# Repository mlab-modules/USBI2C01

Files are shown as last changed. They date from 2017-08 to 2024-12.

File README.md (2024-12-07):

# USBI2C01A - USB to I²C master converter

USBI2C01A is USB to I²C master adapter, it provides you ability to connect almost any I2C/SMBUS sensor or other device to a computer trought USB.
Converter is based on [CP2112](https://www.silabs.com/interface/usb-bridges/classic/device.cp2112?tab=specs) integrated USB brigde with native Linux kernel support. 
Therefore device create kernel accesible I2C interface intstantly on almost any Linux distributions.
If your computer doesn't support CP2112 converter, it's possible to use the USB-HID interface of the converter.
Thanks to that, the device can be used with other operating systems as well, as Windows or Android.

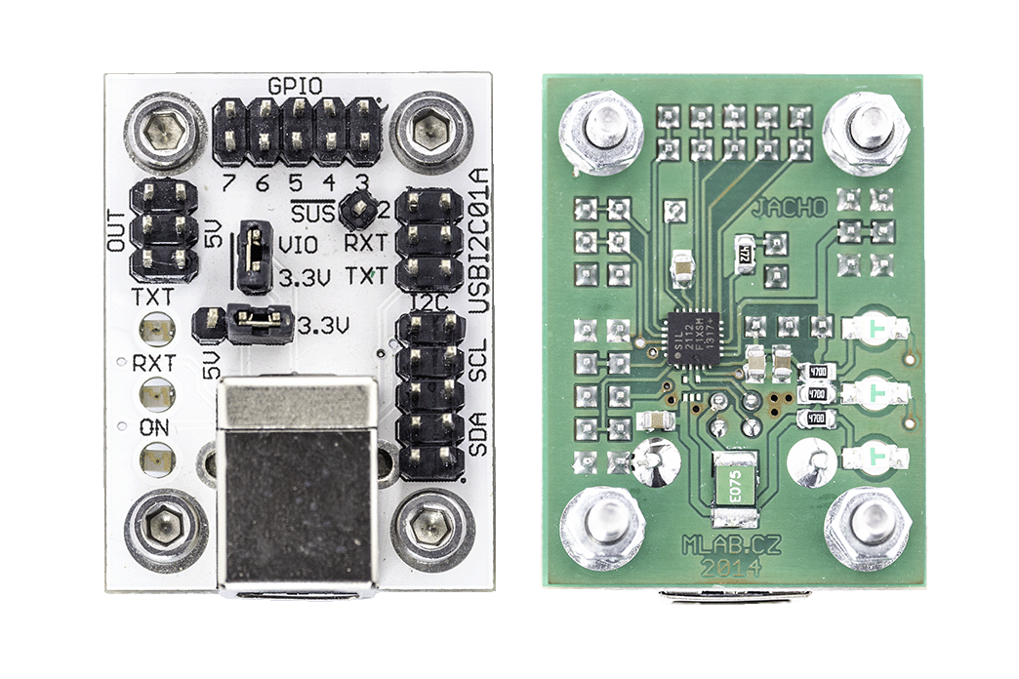
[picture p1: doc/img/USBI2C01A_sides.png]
USBI2C01A


The module is connected to computer using a USB-B connector, which provides a quality connection to the computer. The module contains three LED diodes that indicate power and communication via the I2C bus in the default configuration. The communication pins are doubled, so you will have enough space to connect your circuit.

I2C is connected to the 5-pin header in the MLAB I2C pinout. This is specific in that the rotation of cable (connector) will only result in not functioning state. However, there is no risk of electrical damage. Using jumpers, it is possible to set the power supply voltage in the I2C bus connector. This can either be 5V from USB, which is protected by a 750 mA fuse, or 3.45V from the integrated LDO with a maximum allowed load of 100 mA.

The converter is equipped with a set of GPIO ports that can be controlled via USB. In addition to communication via I2C, you can, for example, check the status of digital signals or control them with software. Similarly, you can use LEDs on the module to indicate your own states because they are software-controllable. 

### Parameters
 * USB-HID to SMBus (I2C) master bridge
 * 8 GPIO ports (2 equipted with LED indicators)
   * Configurable as Input/Output, Open-drain/Push-pull
   * Configurable as clock output (48 MHz to 94 kHz)
 * Selectable 5V or 3.3V power supply
 * USB-B - FullSpeed USB support (up to 12 Mbps)
   * Powered from USB
 * Support in linux kernel
 * Configurable clock speed, 7bit i2c adressing
 * Ready to use 

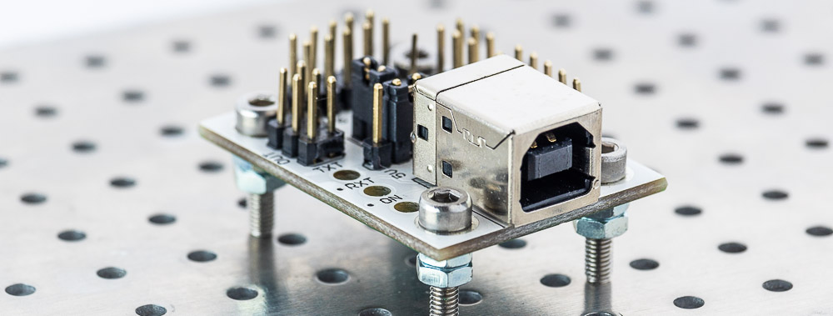
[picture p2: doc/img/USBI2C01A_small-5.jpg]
USBI2C01A USB to I2C master converter



## How to get this device? 

This device is sold by [Universal Scientific Technologies s.r.o.](www.ust.cz). You can buy it online trought [Tindie MLAB store](https://www.tindie.com/products/33745/) or interested in more our products, do not be afraid to [contact us](mailto:sale@ust.cz
).

## Drivers and software
The USB device behaves as a standard [USB-HID](https://en.wikipedia.org/wiki/USB_human_interface_device_class) device, so you do not need non-standard drivers. It also allows control of devices in the I2C system bus.

In case of Linux the drivers are available in kernel. Therefore the module creates the system-wide I2C bus. This is the same interface that you can known from thesingle-board computers like Raspberry Pi. Thanks to this, you will be able to run your Raspberry Pi programs directly on your computer.

## Usage
The functional examples are available in [pymblab](https://github.com/MLAB-project/pymlab) control library. The details are available on [MLAB wiki](https://wiki.mlab.cz/doku.php?id=en:usbi2c). The Pymlab library supports accessing the device both through the I2C interface in the Linux kernel and through the USB-HID interface. Thanks to this, you can use these modules on different operating systems.

## Hardware
schematics

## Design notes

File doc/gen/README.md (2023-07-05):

# PCB

Board size: 29.97x40.13 mm (1.18x1.58 inches)

- This is the size of the rectangle that contains the board
- Thickness: 1.6 mm (63 mils)
- Material: FR4
- Finish: HAL lead-free
- Layers: 2
- Copper thickness: 35 µm

Solder mask: TOP / BOTTOM

- Color: White

Silk screen: TOP / BOTTOM

- Color: Black

Special features:

- Castellated pads

Stackup:

| Name | Type | Color | Thickness | Material | Epsilon_r | Loss tangent |
|---|---|---|---|---|---|---|
| F.SilkS | Top Silk Screen | Black | | | | |
| F.Paste | Top Solder Paste | | | | | |
| F.Mask | Top Solder Mask | White | 10 | | | |
| F.Cu | copper | | 35 | | | |
| dielectric 1 | core | | 1510 | FR4 | 4.5 | 0.020 |
| B.Cu | copper | | 35 | | | |
| B.Mask | Bottom Solder Mask | White | 10 | | | |
| B.Paste | Bottom Solder Paste  | | | | | |
| B.SilkS | Bottom Silk Screen | Black | | | | |

# Important sizes

Clearance: 0.15 mm (6 mils)

Track width: 0.25 mm (10 mils)

- By design rules: 0.2 mm (8 mils)

Drill: 0.6 mm (24 mils)

- Vias: 0.6 mm (24 mils) [Design: 0.4 mm (16 mils)]
- Pads: 1.0 mm (39 mils)
- The above values are real drill sizes, they add 0.1 mm (4 mils) to plated holes (PTH)

Via: 0.91/0.5 mm (36/20 mils)

- By design rules: 0.4/0.3 mm (16/12 mils)
- Micro via: yes [0.2/0.1 mm (8/4 mils)]
- Buried/blind via: yes
- Total: 11 (thru: 11 buried/blind: 0 micro: 0)

Outer Annular Ring: 0.15 mm (6 mils)

- By design rules: 0.21 mm (8 mils)

Eurocircuits class: 6A
- Using min drill 0.6 mm for an OAR of 0.15 mm

# General stats

Components count: (SMD/THT)

- Top: 0/12 (THT)
- Bottom: 4/10 (SMD + THT)

Defined tracks:

Used tracks:

- 0.25 mm (10 mils) (10) defined: no
- 0.3 mm (12 mils) (90) defined: no
- 0.41 mm (16 mils) (56) defined: no
- 0.61 mm (24 mils) (37) defined: no

Defined vias:

Used vias:

- 0.91/0.5 mm (36/20 mils) (Count: 7, Aspect: 1.8 A) defined: no
- 1.01/0.6 mm (40/24 mils) (Count: 4, Aspect: 1.6 A) defined: no

Holes (excluding vias):

- 0.89 mm (35 mils) (36)
- 0.91 mm (36 mils) (2)
- 0.92 mm (36 mils) (4)
- 2.3 mm (91 mils) (2)
- 2.7 mm (106 mils) (3)
- 3.2 mm (126 mils) (4)

Oval holes:

Drill tools (including vias and computing adjusts and rounding):

- 0.6 mm (24 mils) (7)
- 0.7 mm (28 mils) (4)
- 1.0 mm (39 mils) (42)
- 2.4 mm (94 mils) (2)
- 2.7 mm (106 mils) (3)
- 3.3 mm (130 mils) (4)

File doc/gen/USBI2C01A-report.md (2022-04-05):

# PCB

Board size: 29.97x40.13 mm (1.18x1.58 inches)

- This is the size of the rectangle that contains the board
- Thickness: 1.6 mm (63 mils)
- Material: FR4
- Finish: HAL lead-free
- Layers: 2
- Copper thickness: 35 µm

Solder mask: TOP / BOTTOM

- Color: White

Silk screen: TOP / BOTTOM

- Color: Black

Special features:

- Castellated pads

Stackup:

| Name | Type | Color | Thickness | Material | Epsilon_r | Loss tangent |
|---|---|---|---|---|---|---|
| F.SilkS | Top Silk Screen | Black | | | | |
| F.Paste | Top Solder Paste | | | | | |
| F.Mask | Top Solder Mask | White | 10 | | | |
| F.Cu | copper | | 35 | | | |
| dielectric 1 | core | | 1510 | FR4 | 4.5 | 0.02 |
| B.Cu | copper | | 35 | | | |
| B.Mask | Bottom Solder Mask | White | 10 | | | |
| B.Paste | Bottom Solder Paste  | | | | | |
| B.SilkS | Bottom Silk Screen | Black | | | | |

# Important sizes

Clearance: 0.15 mm (6 mils)

Track width: 0.25 mm (10 mils)

- By design rules: 0.2 mm (8 mils)

Drill: 0.5 mm (20 mils)

- Vias: 0.5 mm (20 mils) [Design: 0.3 mm (12 mils)]
- Pads: 0.89 mm (35 mils)

Via: 0.91/0.5 mm (36/20 mils)

- By design rules: 0.4/0.3 mm (16/12 mils)
- Micro via: no [0.2/0.1 mm (8/4 mils)]
- Burried/blind via: no

Outer Annular Ring: 0.41 mm (16 mils)

- By design rules: 0.5 mm (20 mils)

Eurocircuits class: 6B

# General stats

Components count: (SMD/THT)

- Top: 0/12 (THT)
- Bottom: 4/10 (SMD + THT)

Defined tracks:

Used tracks:

- 0.25 mm (10 mils) (10) defined: no
- 0.3 mm (12 mils) (90) defined: no
- 0.41 mm (16 mils) (56) defined: no
- 0.61 mm (24 mils) (37) defined: no

Defined vias:

Used vias:

- 0.91/0.5 mm (36/20 mils) (Count: 7, Aspect: 1.8 A) defined: no
- 1.01/0.6 mm (40/24 mils) (Count: 4, Aspect: 1.6 A) defined: no

Holes (excluding vias):

- 0.89 mm (35 mils) (36)
- 0.91 mm (36 mils) (2)
- 0.92 mm (36 mils) (4)
- 2.3 mm (91 mils) (2)
- 2.7 mm (106 mils) (3)
- 3.2 mm (126 mils) (4)

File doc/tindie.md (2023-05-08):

## USBI2C01A - USB to I²C Master Converter

The [USBI2C01A](https://github.com/mlab-modules/USBI2C01) is a USB to I²C master adapter that allows you to connect almost any I2C/SMBUS sensor or other device to a computer through USB.
This converter is based on the [CP2112](https://www.silabs.com/interface/usb-bridges/classic/device.cp2112?tab=specs) USB-SMBus/I2C bridge with Linux kernel support, which creates a kernel-accessible I2C interface
directly on almost any Linux distribution. If your computer doesn't support the CP2112 converter, you can use the USB-HID interface of the converter,
making it compatible with other operating systems such as Windows or Android.

Module

The module is connected to the computer using a USB-B connector, which provides a high-quality connection. Converter contains three LED diodes
that indicate power and communication via the I2C bus in the default configuration. Communication pins are doubled, that allows you create complex devices. 

I2C is connected to the 5-pin header in the MLAB I2C pinout (GND-SDA-VCC-SCL-GND). Using jumpers, you can set
the power supply voltage in the I2C bus connector. This can be 5V from USB, which is protected by a 750 mA fuse, or 3.45V from
the integrated LDO with a maximum allowed load of 100 mA.

Converter is equipped with a set of GPIO ports that can be controlled via USB. In addition to communication via I2C,
you can check the status of digital signals or control them with software. Similarly, you can use LEDs on the module to
indicate your own states because they are software-controllable.

#### Parameters
* USB-HID to SMBus (I2C) master bridge
* 8 GPIO ports (2 equipped with LED indicators)
  * Configurable as Input/Output, Open-drain/Push-pull
  * Configurable as clock output (48 MHz to 94 kHz)
* Selectable 5V or 3.3V power supply
* USB-B - FullSpeed USB support (up to 12 Mbps)
  * Powered from USB
* Support in Linux kernel
* Configurable clock speed, 7-bit I2C addressing
* Ready to use

#### Drivers and Software
The USB device behaves as a standard USB-HID device, so you don't need non-standard drivers. It also allows control of devices in the I2C system bus.

In the case of Linux, the drivers are available in the kernel. Therefore, the module creates the system-wide I2C bus. This is the same interface that you can
find on single-board computers like the Raspberry Pi. Thanks to this, you can run your Raspberry Pi programs directly on your computer.

**More informations about device, you can find in [README](https://github.com/mlab-modules/USBI2C01)**

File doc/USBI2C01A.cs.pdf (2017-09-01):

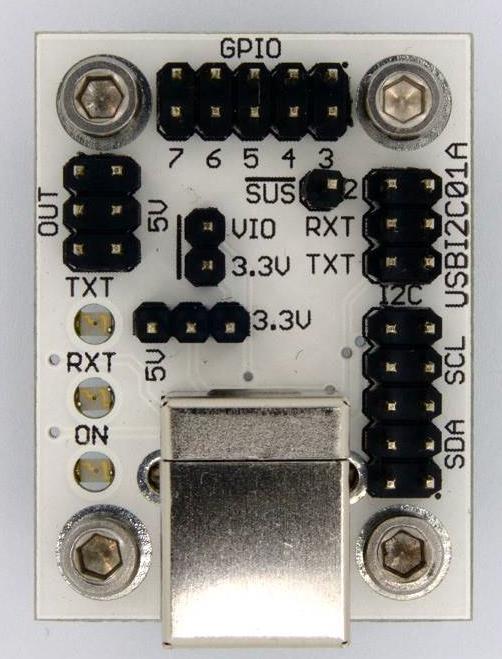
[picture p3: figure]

USBI2C01A.doc / 2017-09-01 / JACHO/ http://www.mlab.cz | 1 / 3
USBI2C01A | MLAB

# Převodník USB na I2C

Jan Chroust

Převodník mezi rozhraními I2C a USB.

# 1. Technické parametry

Parametr | Hodnota | Poznámka
Rozhraní | USBHID 2.0 | Full Speed (12Mbit/s)
Integrovaný obvod | CP2112
Konektor | USB B | Standardní velký USB konektor typu B
Spotřeba | Min. 56 mA | Max. 500 mA
Signály | Serial
Řízení toku | N/A
Režim spánku | 130 uA
Vzbuzení PC | N/A
Rozměry | 41x31x18mm | Výška nad základnou

USBI2C01A | MLAB

# 2. Popis konstrukce

## 2.1. Úvodem

## 2.2. Zapojení modulu

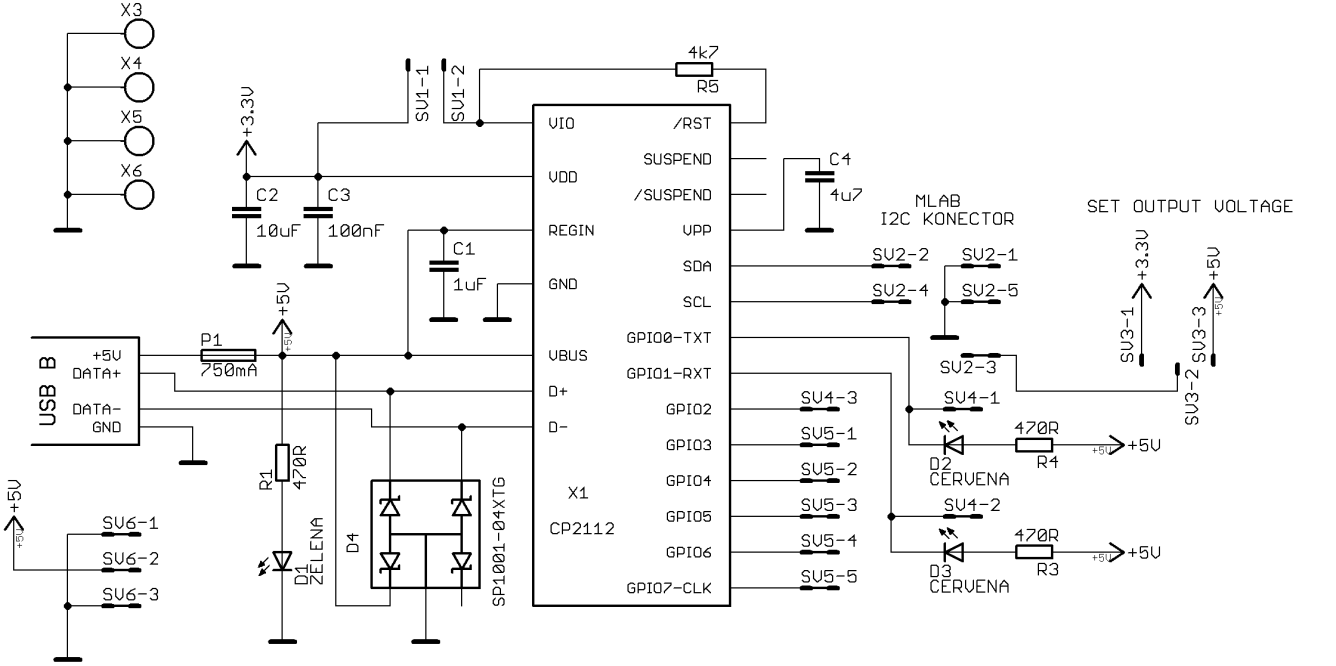
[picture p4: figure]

Označení | Typ (pouzdro)
C1 | 1uF (0805)
C2 | 10uF/10V (0805)
C3 | 100nF (0805)
C4 | 4u7 (0805)
R1, R3, R4 | 470R (0805)
R5 | 4k7 (0805)
D1 | LED ZEL (1206)
D2, D3 | LED ČER (1206)
D4 | Neosazovat
P1 | 750mA (1812)
X1 | CP2112 (QFN-24)
x2 | USB_B
SV1 | JUMP1X2
SV2, SV5 | JUMP2X5
SV3 | JUMP1X3
SV4, SV6 | JUMP2X3

USBI2C01A | MLAB

# 3. Osazení a oživení

## 3.1. Osazení

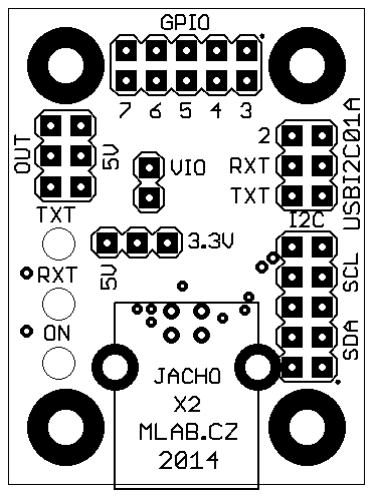
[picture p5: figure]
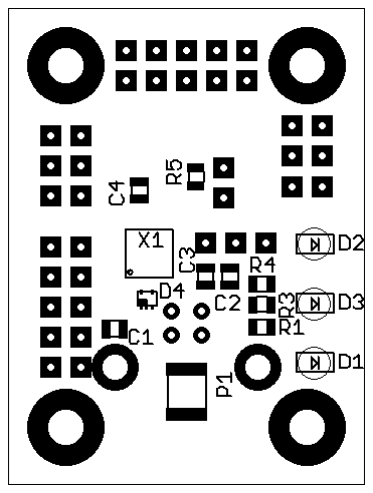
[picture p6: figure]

Umístit jumpery: VIO-3,3V a pro volbu napájení I2C hřebínku zvolit volbu 3,3V

## 3.2. Konfigurace

Konfigurace se zapisuje do interní paměti EEPROM a je nepovinná. Viz kapitola o driverech. Veškeré informace v dokumentačním listu od IO CP2112.

Na pin VIO je možné připojit externí napětí menší než 3,3 V a určuje napěťové úrovně logiky I2C. Například 1,8 V. Standardně se pomocí jumperu přivede na tento pin napětí 3,3 V.

Pomocí jumperu na hřebínku 1x3 je možné zvolit napájení, které bude vyvedeno na I2C hřebínek. Buď 3,3V, 5V a v případě žádného jumperu žádné napájení.

# 4. Datové listy

CP2012.pdf - SINGLE CHIP HID USB TO SMBUS MASTER BRIDGE

AN495.pdf - CP2112 INTERFACE SPECIFICATION

AN496.pdf - HID USB-TO-SMBUS API SPECIFICATION

AN721.pdf - CP21XX DEVICE CUSTOMIZATION GUIDE

Http://www.silabs.com

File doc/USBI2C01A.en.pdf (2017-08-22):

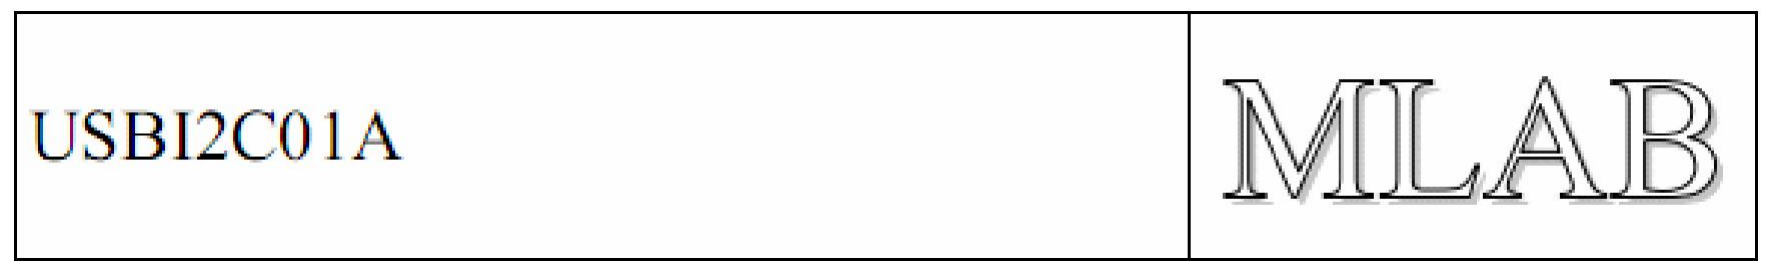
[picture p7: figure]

## USBHID TO I2C/TWI

Jan Chroust

The conversion from USB to I2C.

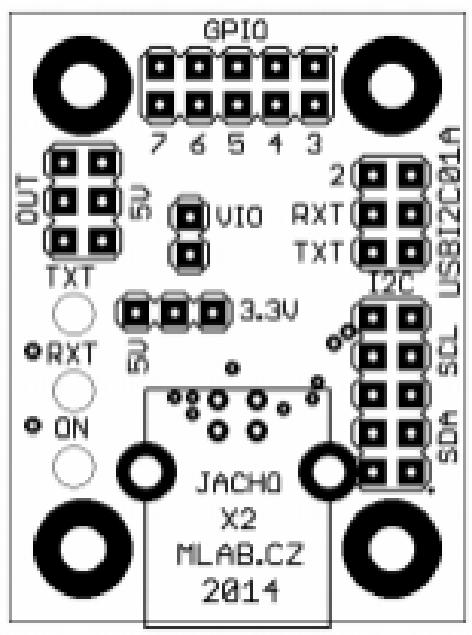
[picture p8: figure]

## Technical Parameters

Parameter | Value | Description
Interface | USBHID 2.0 | Full Speed (12Mb/s)
Connector | USB B | Full Size USB B Female
Power Consumption | 56mA Minimum | 500mA Maximum
Signals | Serial | Serial & Digital
Flow Control | N/A | N/A
Sleep | 130µA
Power Management PC | N/A | N/A
Board Dimensions | 51x31x18mm

## PCB Overview & Parts List

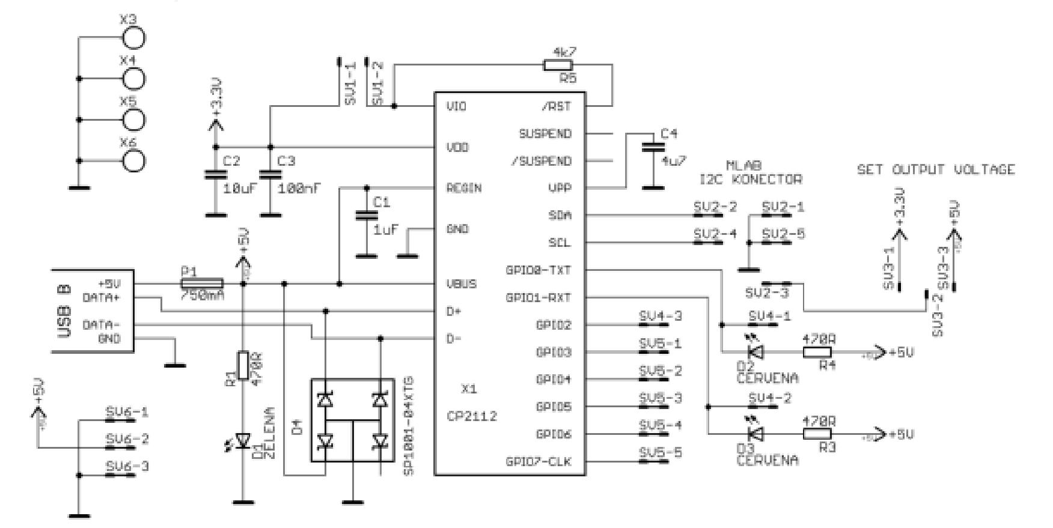
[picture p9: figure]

## Parts List

Components | Values | Package
C1 | 1µF | 0805
C2 | 10µF | 0805
C3 | 100µF | 0805
C4 | 4.7µF | 0805
R1 , R3 , R4 | 470R | 0805
R5 | 4K7 | 0805
D1 | LED On | 1206
D2 , D3 | LED Transmission | 1206
D4 | SP1001-04XTG | SOT553
P1 | 750mA | 1812
X1 | CP2112 | QFN24
X2 | | USB-B
SV1 | Jumper | 1Row 2Pins
SV2 , SV5 | Jumper | 2Rows 5Pins
SV3 | Jumper | 1Row 3Pins
SV4 , SV6 | Jumper | 2Rows 3Pins

## Silkscreen & Component Layout

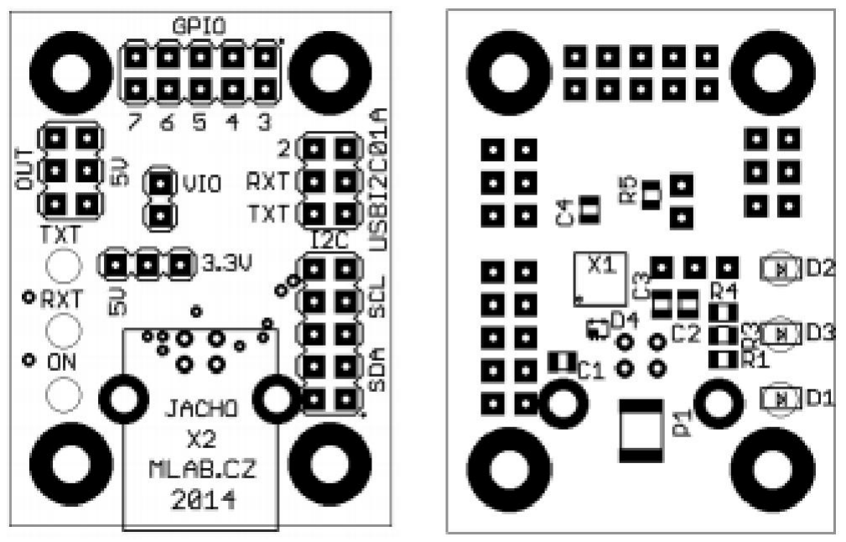
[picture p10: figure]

## Customisation & Configuration

Silabs CP2112 provides OTP to specify unique Vendor & Product information.
End user can configure GPIO , Power Management & other programmable settings.

Refer to manafacturers Datasheets & Application Notes.

## Reference Materials

CP210x-CP211x-Overview-Technical.pdf

## Datasheets

CP2112.pdf – SINGLE CHIP HID USB TO SMBUS MASTER BRIDGE

AN495.pdf - CP2112 INTERFACE SPECIFICATION

AN496.pdf - HID USB-TO-SMBUS API SPECIFICATION

AN721.pdf - CP21XX DEVICE CUSTOMIZATION GUIDE

Http://www.silabs.com

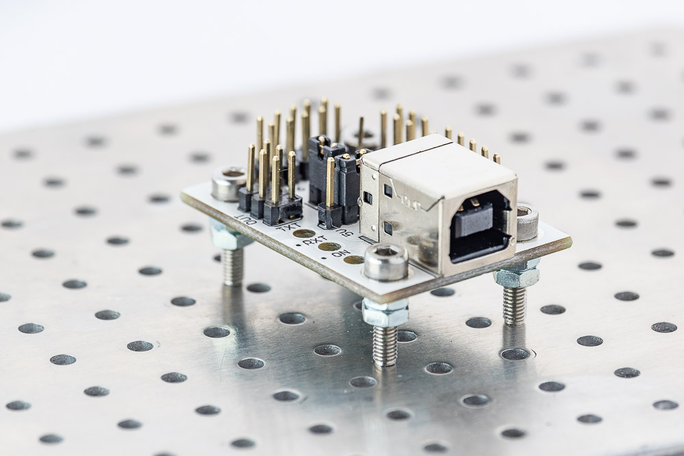
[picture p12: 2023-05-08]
doc/img/USBI2C01A_small-4.jpg

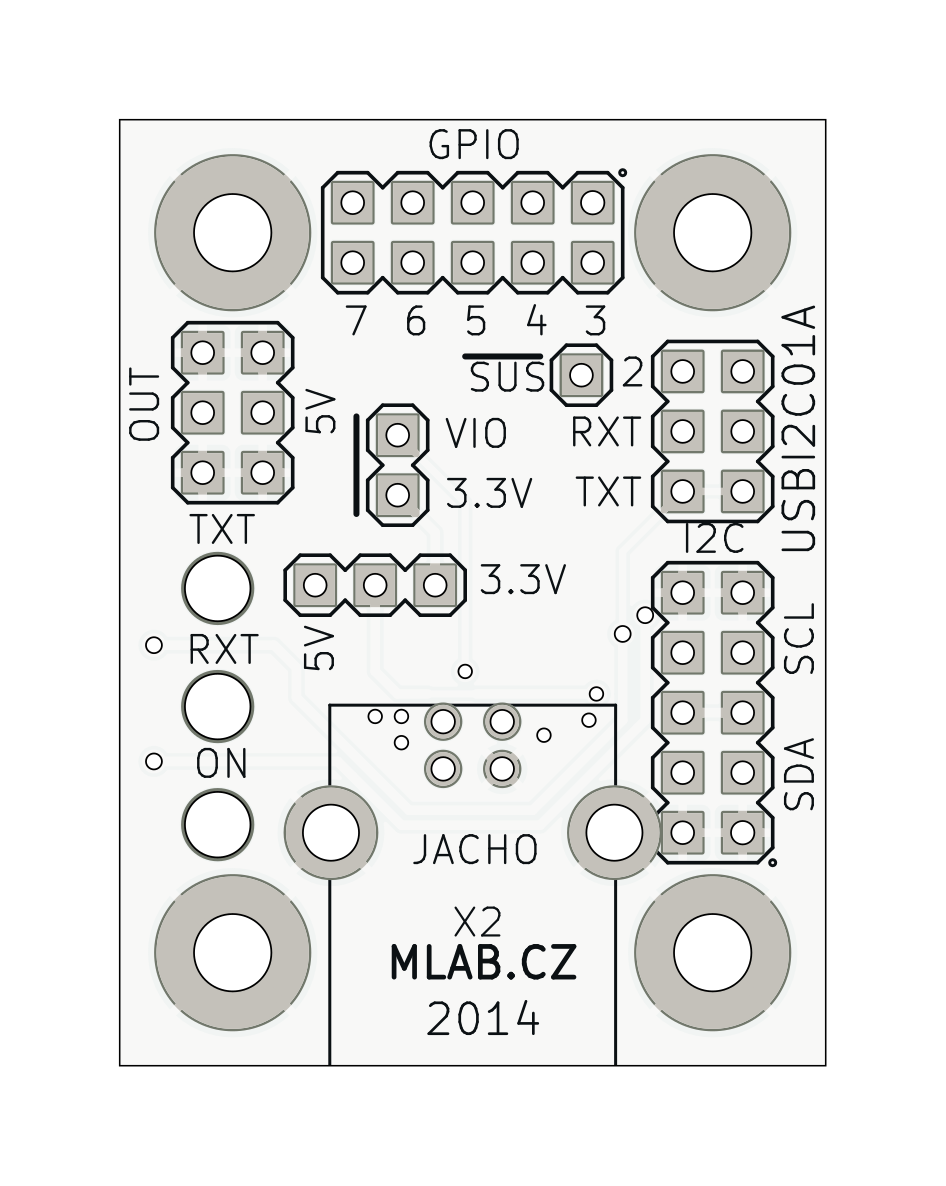
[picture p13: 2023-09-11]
doc/gen/img/USBI2C01-top.png

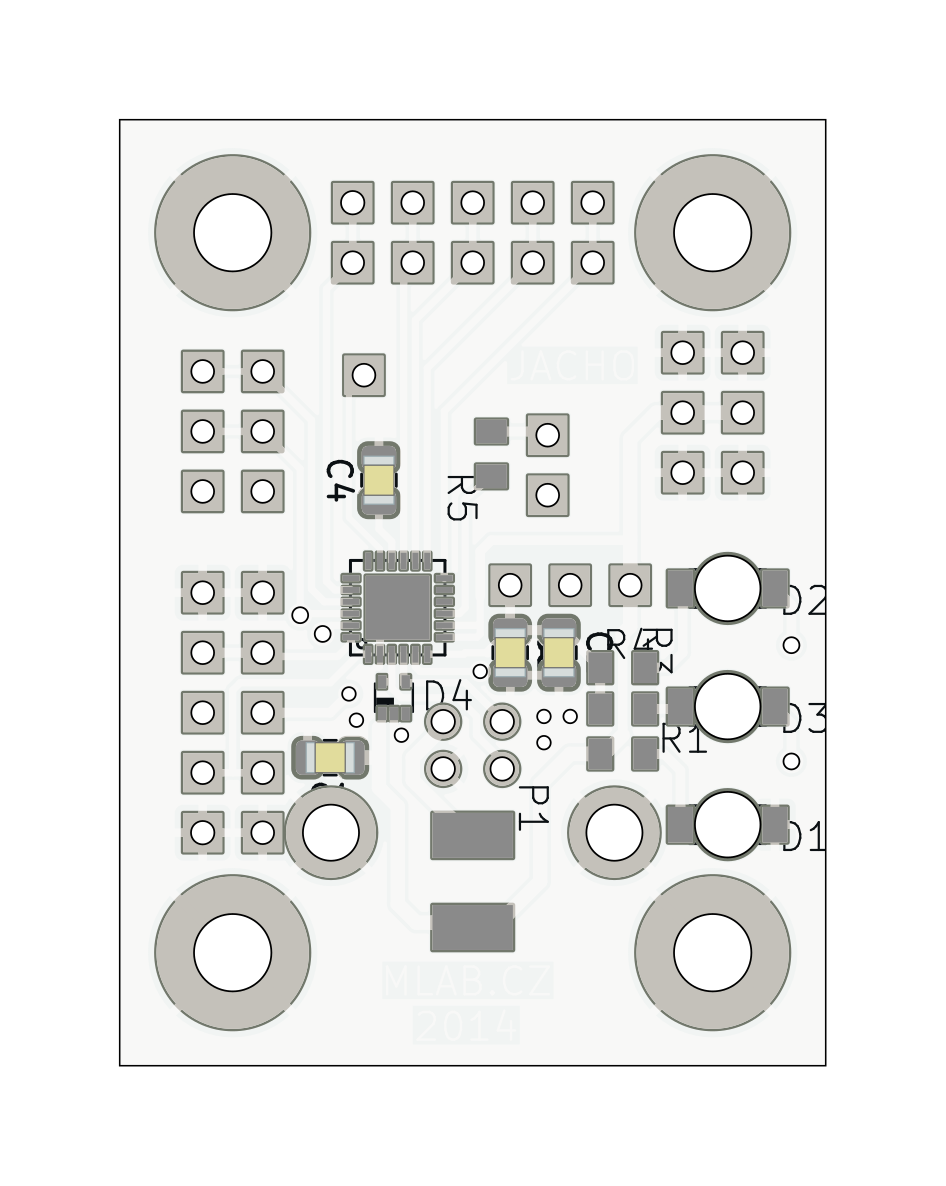
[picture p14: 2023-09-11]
doc/gen/img/USBI2C01-bottom.png

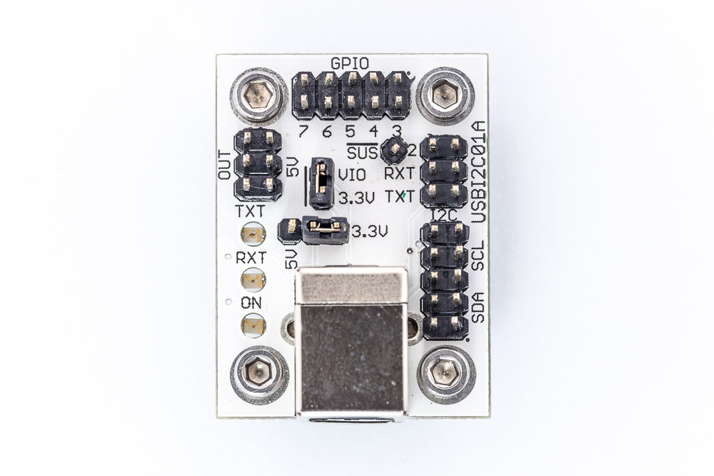
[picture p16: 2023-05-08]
doc/img/USBI2C01A_small-7.jpg

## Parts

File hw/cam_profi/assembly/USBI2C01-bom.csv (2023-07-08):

Component | Description | Part | References | Value | Footprint | Quantity Per PCB | Datasheet | ust_id
1 |  | C0805 | C3 | 100nF | C_0805_2012Metric | 1 |  | 5c70984712875079b91f8b4c
2 |  | C0805 | C1 | 1uF | C_0805_2012Metric | 1 |  | 5c70984712875079b91f8b50
3 |  | C0805 | C4 | 4u7 | C_0805_2012Metric | 1 |  | 5e3ff8fc1287502a33bad7a3
4 |  | C0805 | C2 | 10uF | C_0805_2012Metric | 1 |  | 5c70984812875079b91f8bbd
5 |  | LED1206_2 | D1 | Green | 1206_2 | 1 |  | 5c70984412875079b91f8895
6 |  | LED1206_2 | D2D3 | Red | 1206_2 | 2 |  | 5c70984412875079b91f8896
7 |  | D_4xZENER | D4 | SP1001-04XTG | SOT553 | 1 |  | 5c70984512875079b91f88cc
8 |  | POJISTKA_1812 | P1 | 750mA | 1812 | 1 |  | 5c70984512875079b91f88d2
9 |  | R0805 | R1R3R4 | 470R | 0805 | 3 |  | 5c70984512875079b91f8986
10 |  | R0805 | R5 | 4k7 | 0805 | 1 |  | 5c70984612875079b91f8995
11 | 1x01 2.54 mm pitch header | HEADER_1x01 | SV7 | MA01-1 | MA01-1 | 1
12 | 1x02 2.54 mm pitch header | HEADER_1x02 | SV1 | MA02-1 | MA02-1 | 1
13 | 1x03 2.54 mm pitch header | HEADER_1x03 | SV3 | MA03-1 | MA03-1 | 1
14 | 2x03 2.54 mm pitch header, 2 pins next to each other are connected | HEADER_2x03_PARALLEL | SV4SV6 | MA03-2 | MA03-2 | 2
15 | 2x05 2.54 mm pitch header, 2 pins next to each other are connected | HEADER_2x05_PARALLEL | SV2SV5 | MA05-2 | MA05-2 | 2
16 |  | CP2112 | X1 | CP2112 | QFN-24 | 1 |  | 5c70984612875079b91f89b2
17 |  | SROUB3M | X3X4X5X6 | SROUB3M | SROUB3M | 4
18 |  | USB_B | X2 | USB_B | USB_B | 1 |  | 5c70984412875079b91f87a8

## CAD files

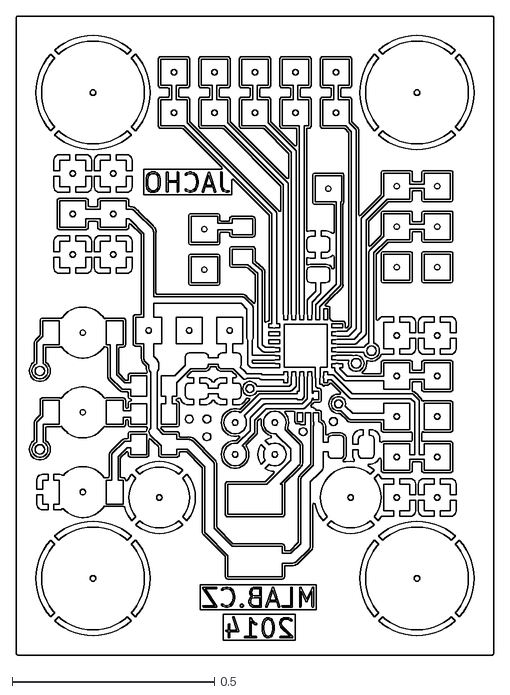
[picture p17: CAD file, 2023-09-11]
doc/gen/dxf/USBI2C01-B_Cu.dxf
1.18 x 1.58

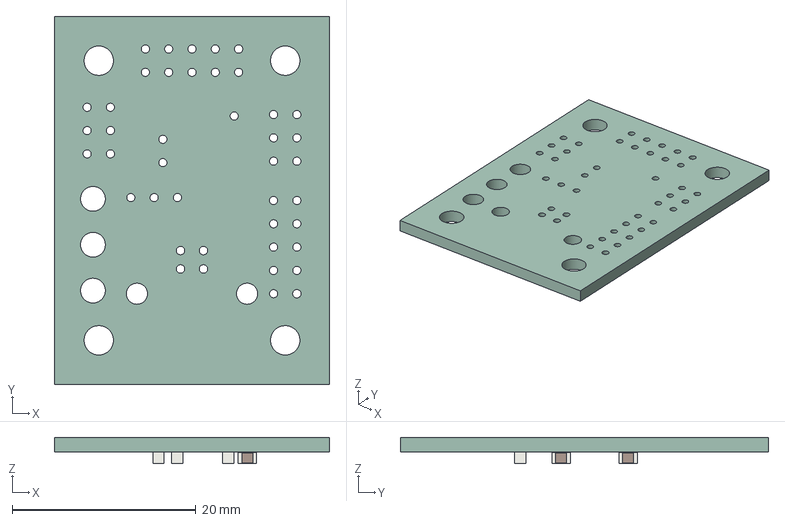
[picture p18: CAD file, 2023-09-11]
doc/gen/USBI2C01.step
30.0 x 40.1 x 2.88 mm
tmptzktr8e5 PCB

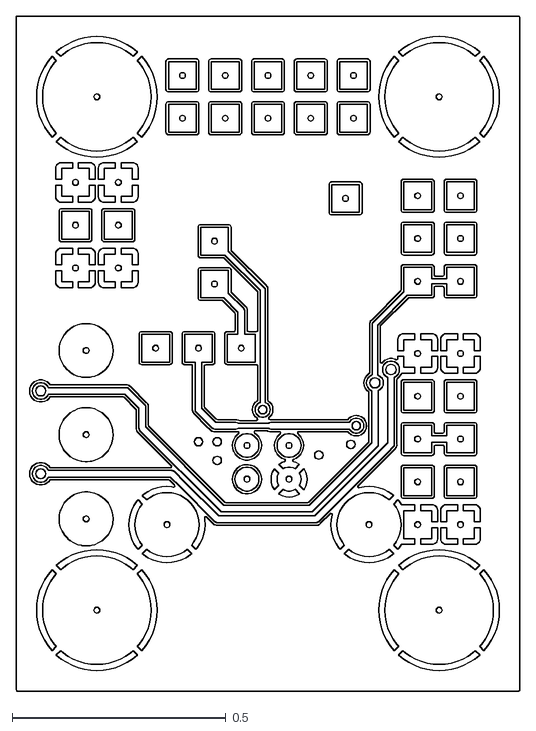
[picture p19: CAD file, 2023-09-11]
doc/gen/dxf/USBI2C01-F_Cu.dxf
1.18 x 1.58

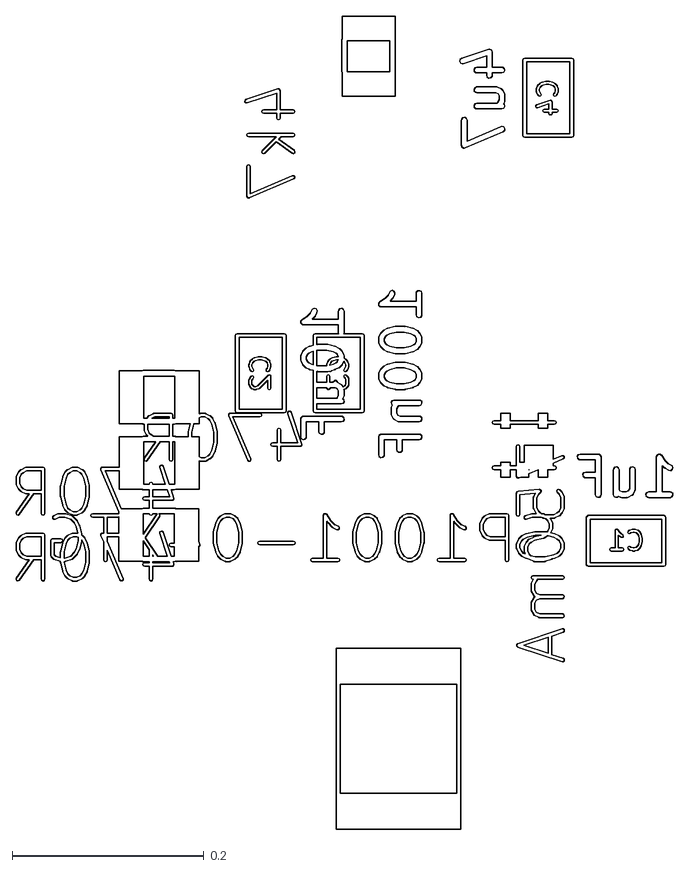
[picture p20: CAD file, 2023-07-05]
doc/gen/dxf/USBI2C01-B_Fab.dxf
0.685 x 0.848

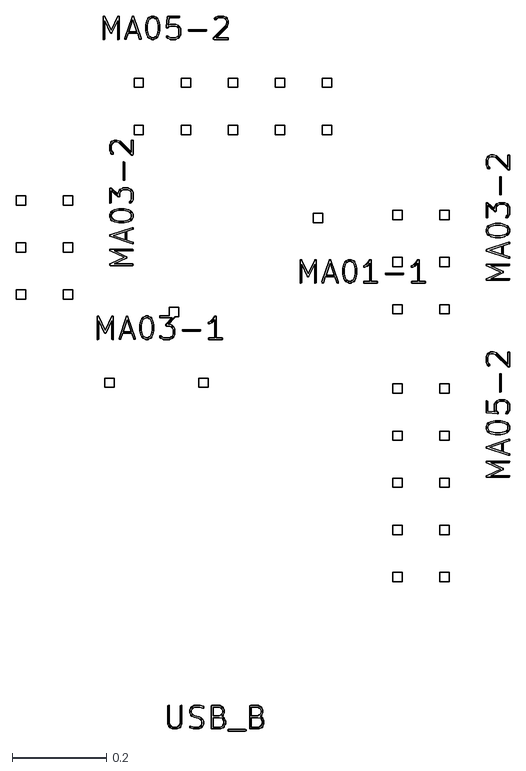
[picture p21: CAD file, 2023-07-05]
doc/gen/dxf/USBI2C01-F_Fab.dxf
1.05 x 1.52

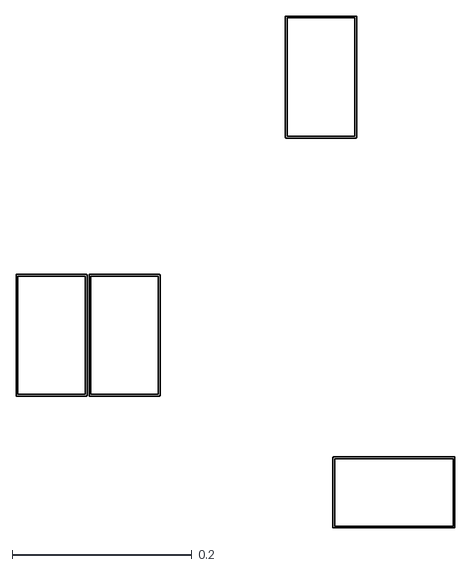
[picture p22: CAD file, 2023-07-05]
doc/gen/dxf/USBI2C01-B_Courtyard.dxf
0.489 x 0.57

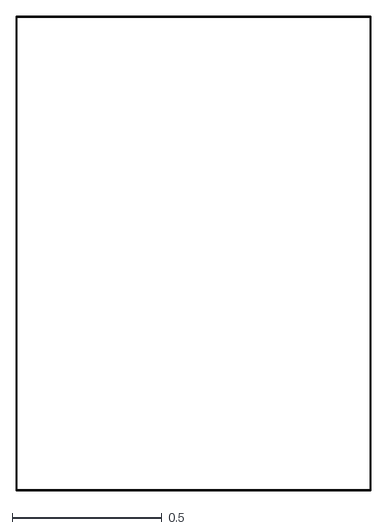
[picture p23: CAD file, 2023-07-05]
doc/gen/dxf/USBI2C01-Edge_Cuts.dxf
1.18 x 1.58

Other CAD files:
doc/gen/dxf/USBI2C01A-User_4.dxf
doc/gen/dxf/USBI2C01-Margin.dxf
doc/gen/dxf/USBI2C01A-User_3.dxf
doc/gen/dxf/USBI2C01A-User_1.dxf
doc/gen/dxf/USBI2C01A-User_2.dxf
doc/gen/dxf/USBI2C01-User_Eco1.dxf
doc/gen/dxf/USBI2C01-User_Drawings.dxf
doc/gen/dxf/USBI2C01A-B_Adhesive.dxf
doc/gen/dxf/USBI2C01A-F_Courtyard.dxf
doc/gen/dxf/USBI2C01-B_Adhesive.dxf
doc/gen/dxf/USBI2C01-F_Adhesive.dxf
doc/gen/dxf/USBI2C01-B_Mask.dxf
doc/gen/dxf/USBI2C01-B_Paste.dxf
doc/gen/dxf/USBI2C01-B_Silkscreen.dxf
doc/gen/dxf/USBI2C01-F_Courtyard.dxf
doc/gen/dxf/USBI2C01-F_Mask.dxf
doc/gen/dxf/USBI2C01-F_Paste.dxf
doc/gen/dxf/USBI2C01-F_Silkscreen.dxf
doc/gen/dxf/USBI2C01-User_Comments.dxf
doc/gen/dxf/USBI2C01-User_Eco2.dxf
doc/gen/dxf/USBI2C01A-F_Adhesive.dxf
doc/gen/dxf/USBI2C01A-F_Paste.dxf
doc/gen/dxf/USBI2C01A-Margin.dxf

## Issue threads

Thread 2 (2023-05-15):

I2C Pull-up strength

kaklik, 2023-05-15:
In some applications, the internal pull-up strength of [CP2112](https://www.silabs.com/interface/usb-bridges/classic/device.cp2112?tab=specs) seems to be insufficient. Could be helpful if there would be an option to increase pull-up strength for some applications.
Suitable options could be activation by jumper or the optional possibility to solder it on the PCB.

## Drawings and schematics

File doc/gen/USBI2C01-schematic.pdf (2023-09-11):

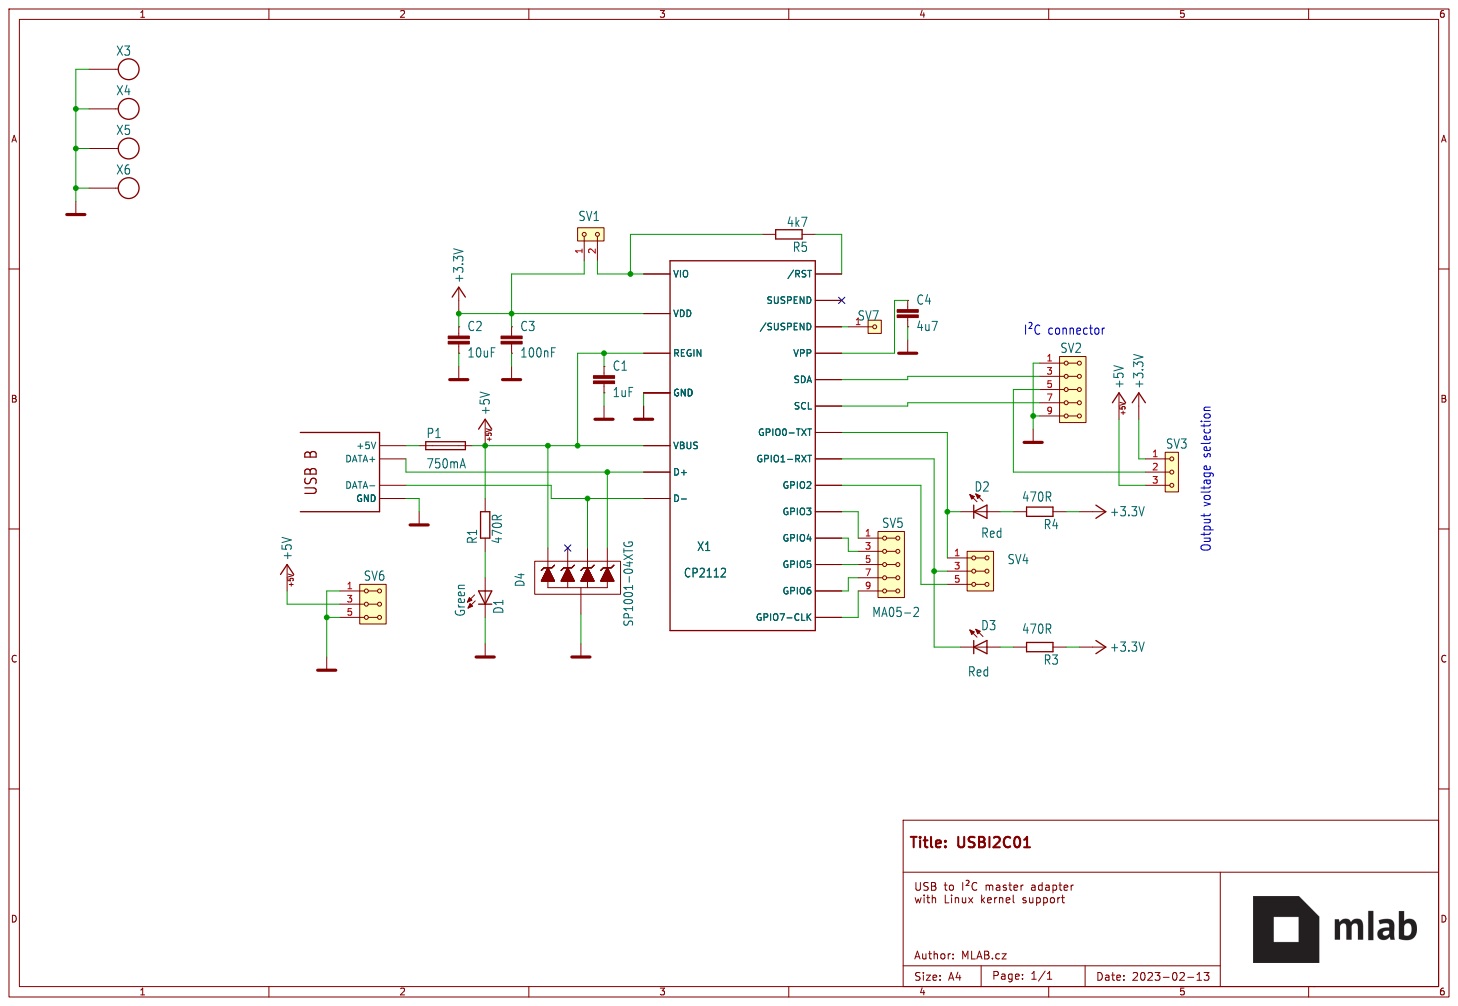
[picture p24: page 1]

USB to þÿI²Cmaster adapter

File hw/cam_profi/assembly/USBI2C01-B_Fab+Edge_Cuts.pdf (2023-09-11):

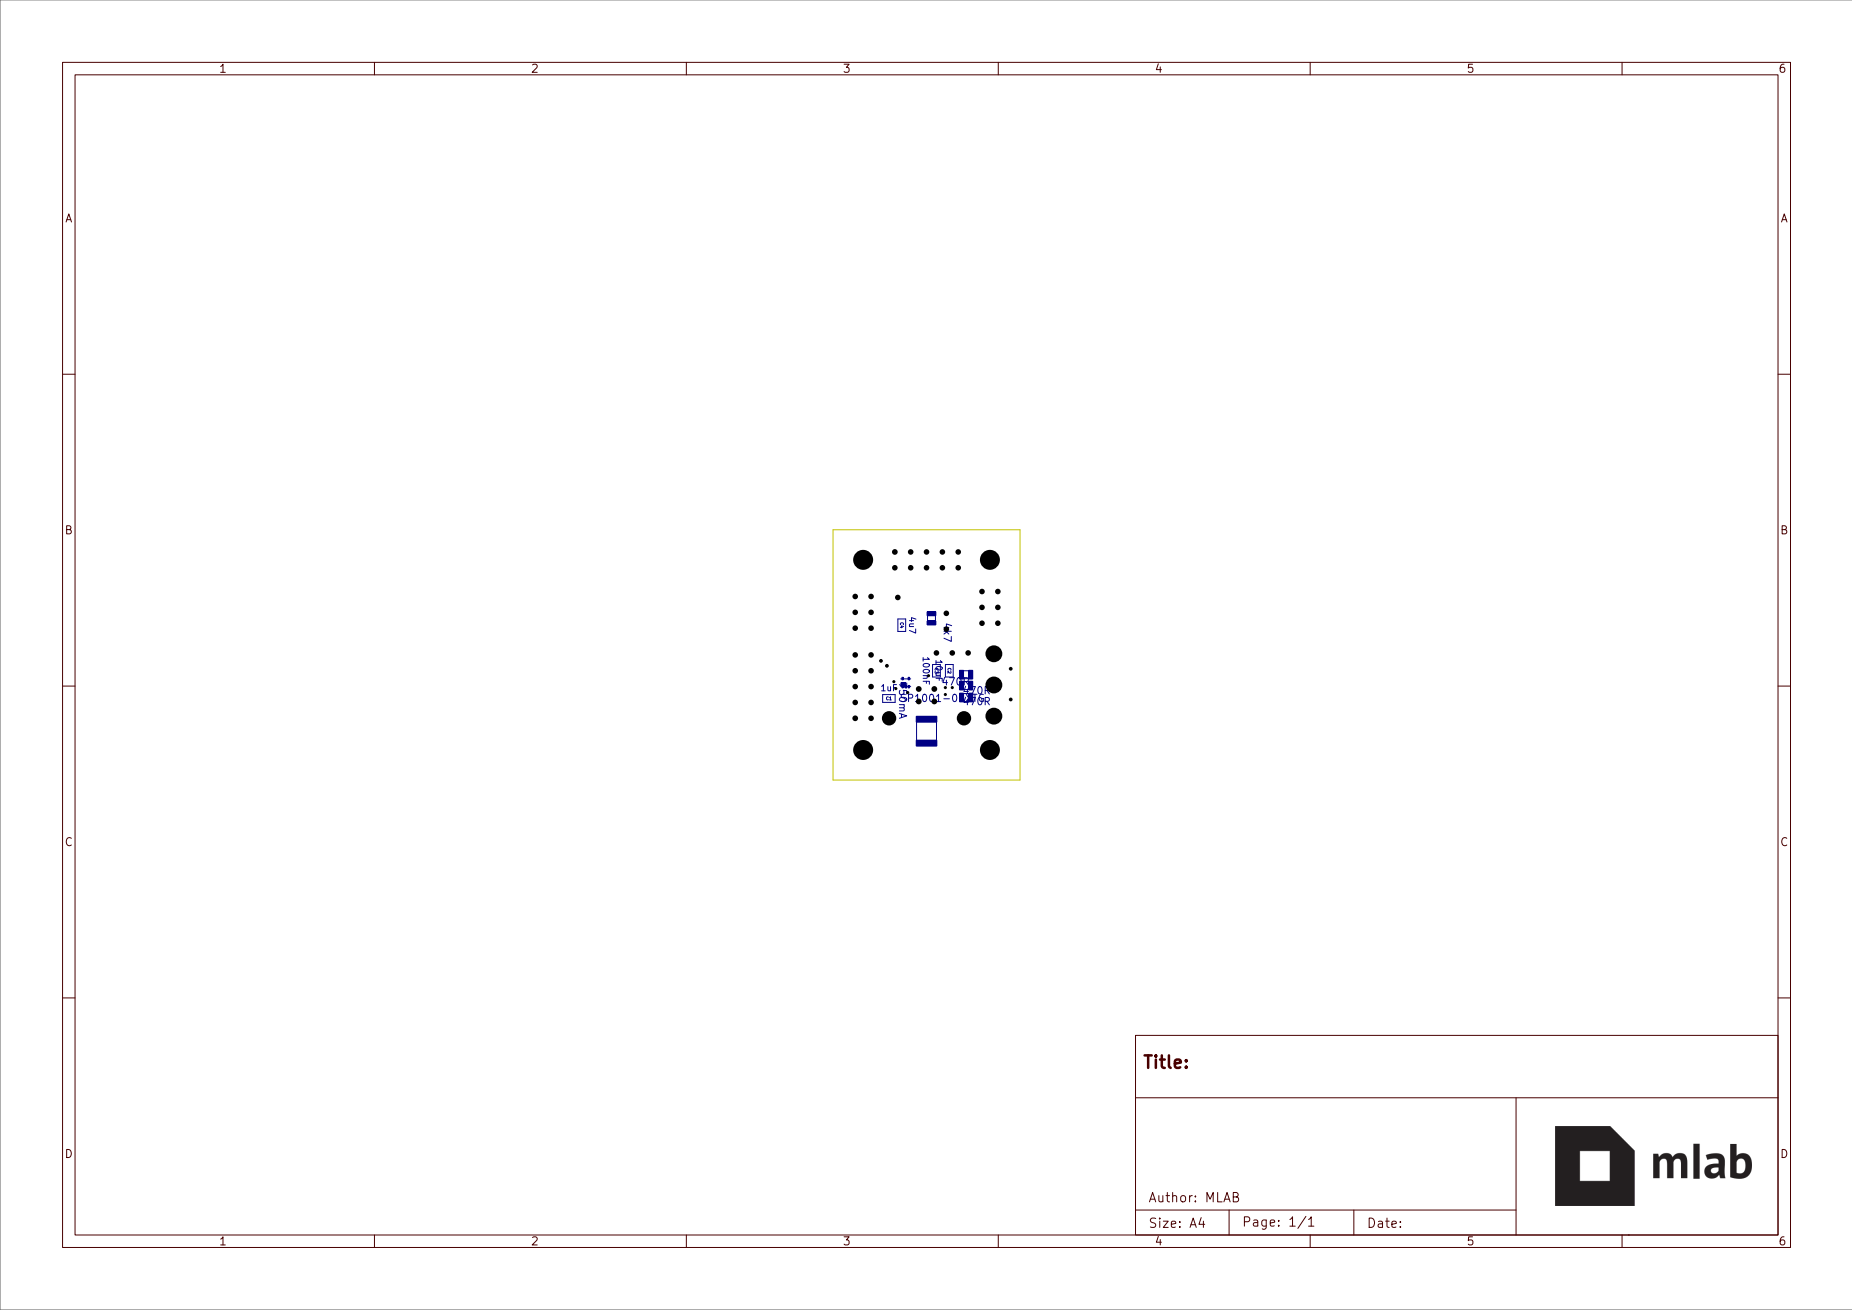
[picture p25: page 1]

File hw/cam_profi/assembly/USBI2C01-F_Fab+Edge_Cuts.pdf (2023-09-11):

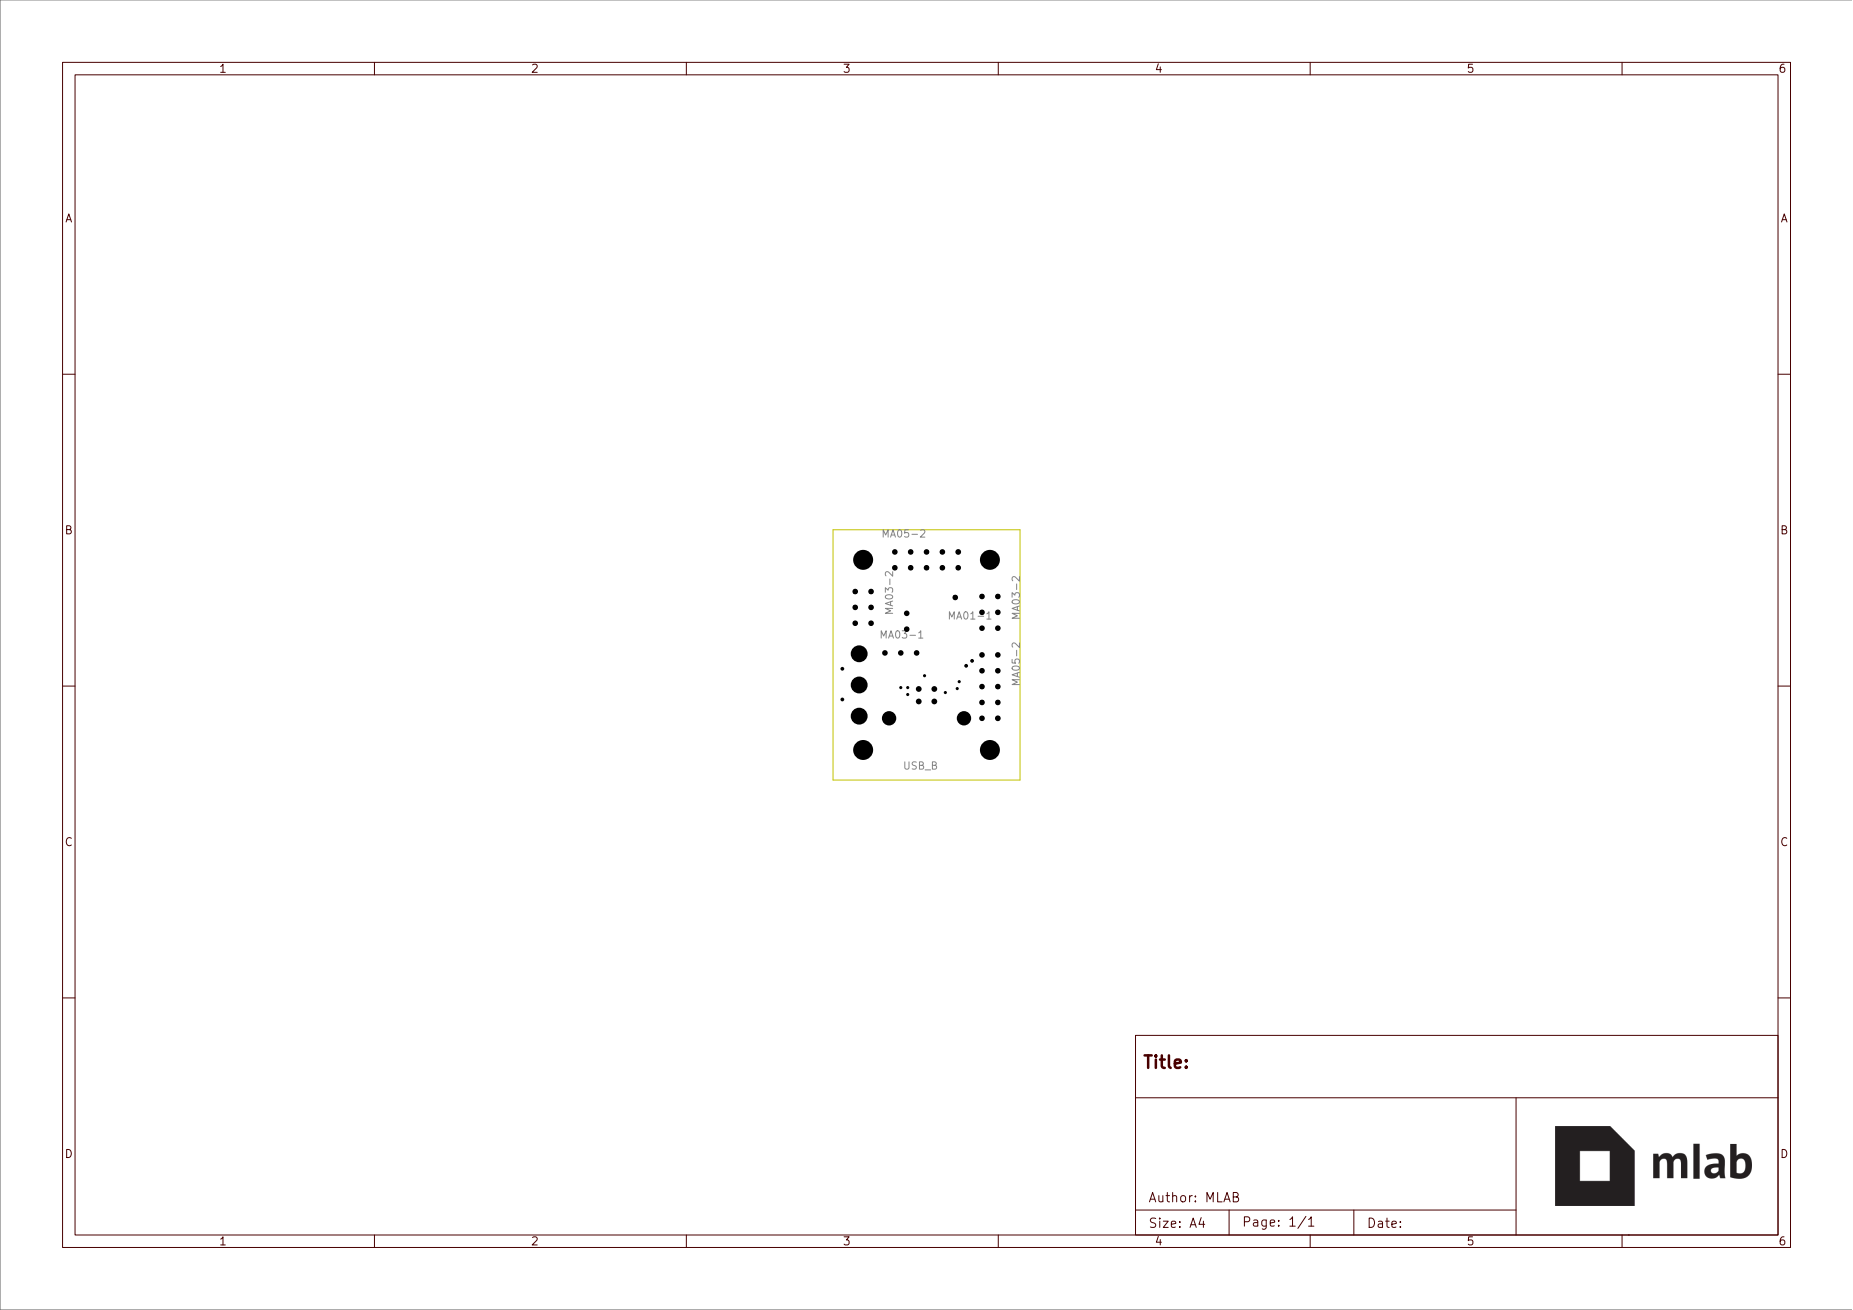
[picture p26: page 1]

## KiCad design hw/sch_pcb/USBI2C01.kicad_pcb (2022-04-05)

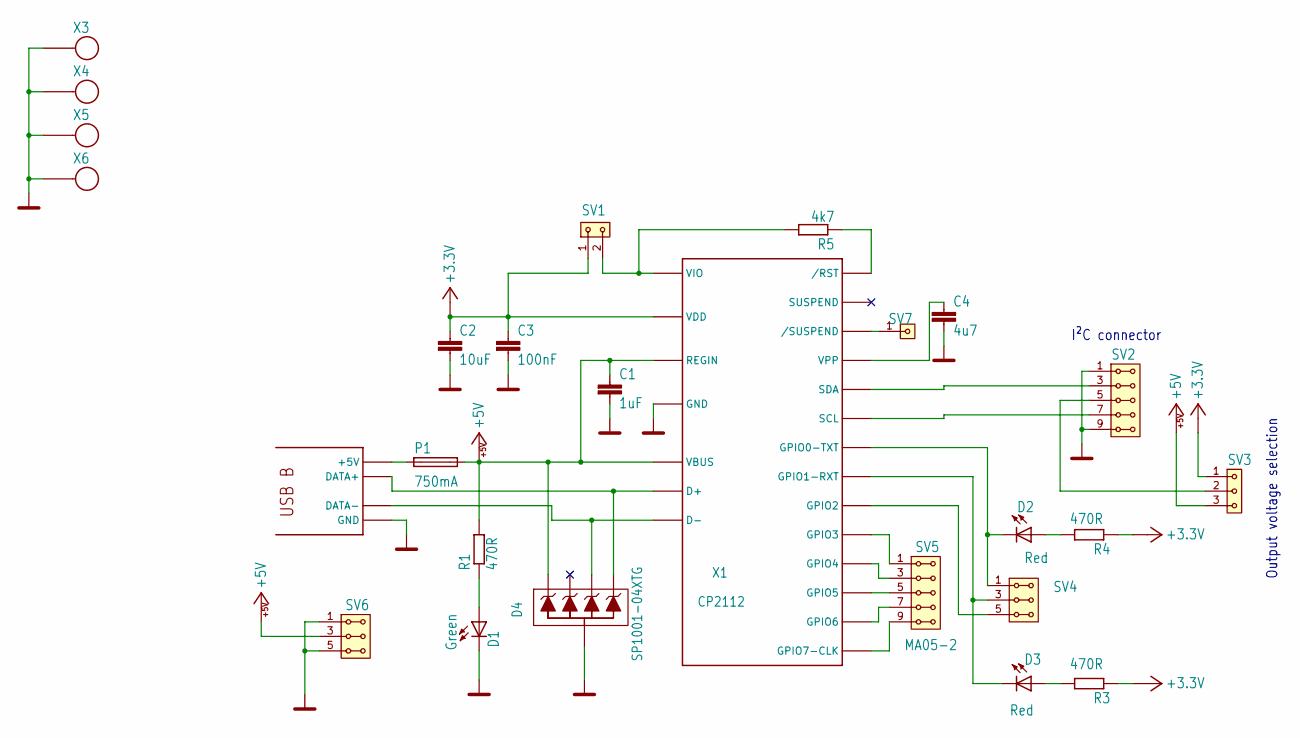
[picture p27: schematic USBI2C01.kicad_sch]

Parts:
C1: 1uF; C_0805_2012Metric
C2: 10uF; C_0805_2012Metric
C3: 100nF; C_0805_2012Metric
C4: 4u7; C_0805_2012Metric
D1: Green; 1206_2
D2, D3: Red; 1206_2
D4: SP1001-04XTG; SOT553
P1: 750mA; 1812
R1, R3, R4: 470R; 0805
R5: 4k7; 0805
SV1: MA02-1
SV2, SV5: MA05-2
SV3: MA03-1
SV4, SV6: MA03-2
SV7: MA01-1
X1: CP2112; QFN-24
X2: USB_B
X3, X4, X5, X6: SROUB3M

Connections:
+3.3V: C2.1, C3.1, R3.1, R4.1, SV1.1, SV3.1, X1.P$6 (VDD)
+5V: C1.1, D4.1, P1.2, R1.2, SV3.3, SV6.3, SV6.4, X1.P$7 (REGIN), X1.P$8 (VBUS)
GND: C1.2, C2.2, C3.2, C4.2, D1.K (C), D4.2, SV2.1, SV2.2, SV2.9, SV2.10, SV6.1, SV6.2, SV6.5, SV6.6, X1.P$2 (GND), X1.P$25 (GND), X2.4 (GND), X2.GND, X2.GND2 (GND), X3.P$1, X4.P$1, X5.P$1, X6.P$1
unnamed: C4.1, X1.P$16 (VPP)
unnamed: D1.A, R1.1
unnamed: D2.A, R4.2
unnamed: D2.K (C), SV4.1, SV4.2, X1.P$23 (GPIO0-TXT)
unnamed: D3.A, R3.2
unnamed: D4.4, X1.P$4 (D-), X2.2 (DATA-)
unnamed: D4.5, X1.P$3 (D+), X2.3 (DATA+)
unnamed: P1.1, X2.1 (+5V)
unnamed: R5.1, X1.P$9 (/RST)
unnamed: R5.2, SV1.2, X1.P$5 (VIO)
unnamed: SV2.5, SV2.6, SV3.2
unnamed: SV5.1, SV5.2, X1.P$20 (GPIO3)
unnamed: SV7.1, X1.P$17 (/SUSPEND)
unnamed: SV2.3, SV2.4, X1.P$1 (SDA)
unnamed: SV5.9, SV5.10, X1.P$12 (GPIO7-CLK)
unnamed: SV5.7, SV5.8, X1.P$13 (GPIO6)
unnamed: SV5.5, SV5.6, X1.P$14 (GPIO5)
unnamed: SV5.3, SV5.4, X1.P$15 (GPIO4)
unnamed: SV4.5, SV4.6, X1.P$21 (GPIO2)
unnamed: D3.K (C), SV4.3, SV4.4, X1.P$22 (GPIO1-RXT)
unnamed: SV2.7, SV2.8, X1.P$24 (SCL)

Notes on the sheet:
I²C connector
Output voltage selection

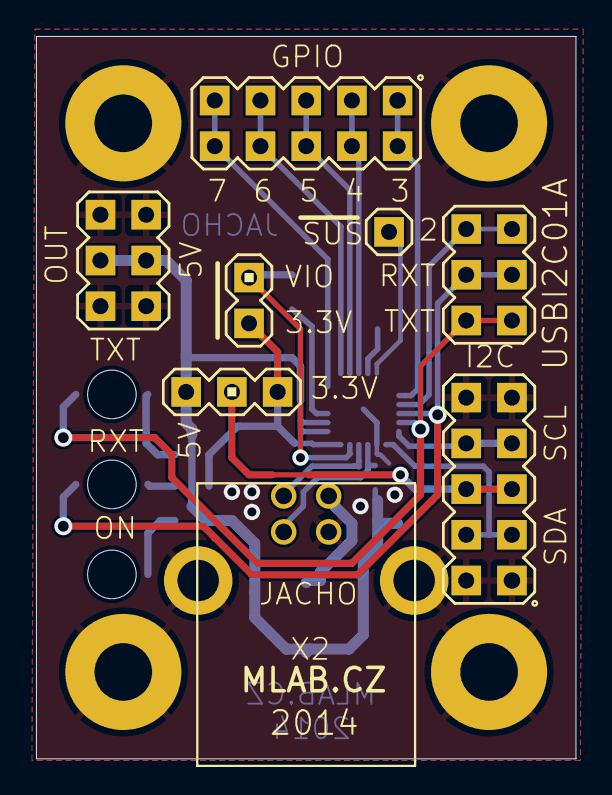
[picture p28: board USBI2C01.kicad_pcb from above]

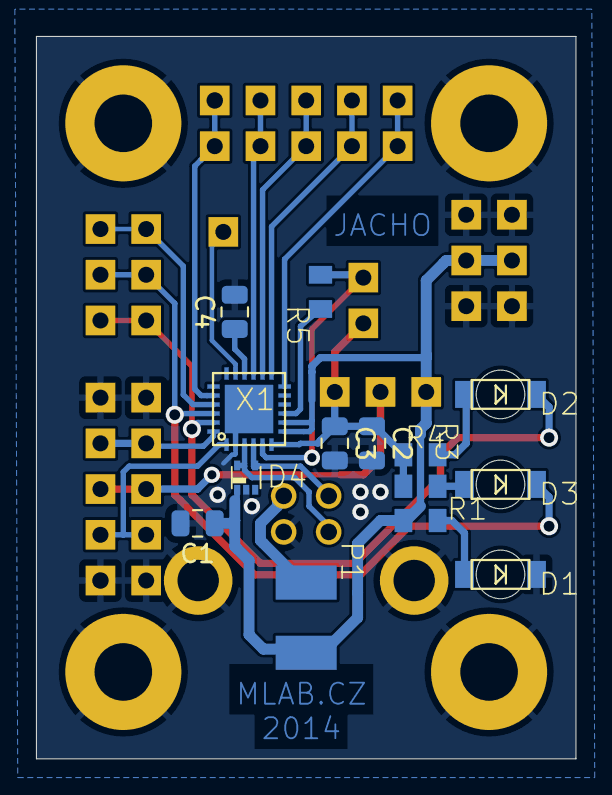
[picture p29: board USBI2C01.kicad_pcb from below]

Board: 2 copper layers, 30.0 x 40.1 mm, 26 parts (14 on the bottom side), 24 nets.

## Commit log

2017-08-22 rename category folders
    [untitled.brd, untitled.sch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]
2017-08-22 rename files and module folders
    [untitled.brd, untitled.sch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]
2017-08-22 create hw folder
    [untitled.brd, untitled.sch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]
2022-04-05 Transfer of the Eagle project to KiCad
    [untitled.brd, untitled.kicad_pcb, untitled.kicad_sch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]
2022-04-05 Renaming the Kicad project
    [USBI2C01A.kicad_pcb, USBI2C01A.kicad_sch]
2022-04-05 Edit schema a vlozeni UST_ID
    [USBI2C01A.kicad_pcb, USBI2C01A.kicad_sch]
2022-04-05 Update actions products
    [USBI2C01A-B_Adhesive.dxf, USBI2C01A-B_Courtyard.dxf, USBI2C01A-B_Cu.dxf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]
2022-04-05 Uprava projektovych dat
    [USBI2C01A.kicad_pcb, USBI2C01A.kicad_sch]
2023-02-13 Translate and cleanup schematics.
    [USBI2C01A.kicad_sch]
2023-02-13 Renaming the KiCAD project to name without revision.
    [USBI2C01.kicad_pcb, USBI2C01.kicad_sch]
2023-02-15 Use kicad_pcb as BOM in kitspace.yaml
